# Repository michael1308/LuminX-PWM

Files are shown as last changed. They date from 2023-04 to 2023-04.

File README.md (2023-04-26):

# LuminX-PWM
ESP32-based LED strip driver.

# Features
-   ESP32-WROOM-32E
-   CH340E/G
-   USB C
-   Micro USB for power
-   2.1mm Barrel Jack w/ reversible polarity    
-   Screw Terminal power input
-   Current Measurement w/ INA219/INA180
-   5V Buck Converter
-   3.3V LDO
-   Microphone
-   IR Receiver
-   5x PWM out
-   Power Switching Relay
-   Temperature Sensor DS18B20
-   I2C Connector
-   ESP32 Debug Connector
-   Up to 10A

# Rev 1.0 (03.2023)
## Issues:
- Reverse Polarity Protection MOSFET reversed
- INA180 Resistor too large -> change to 10mOhm
- USBLC6 wrong footprint -> SOT-6

## Changes:
- Remove Micro USB
- Route Input Voltage directly to output
- Change reverse polarity protection to antiparallel diode (M7)
- Better Integration for Temp Sensor
- Smaller Footprint
- Automotive or Glass fuse?

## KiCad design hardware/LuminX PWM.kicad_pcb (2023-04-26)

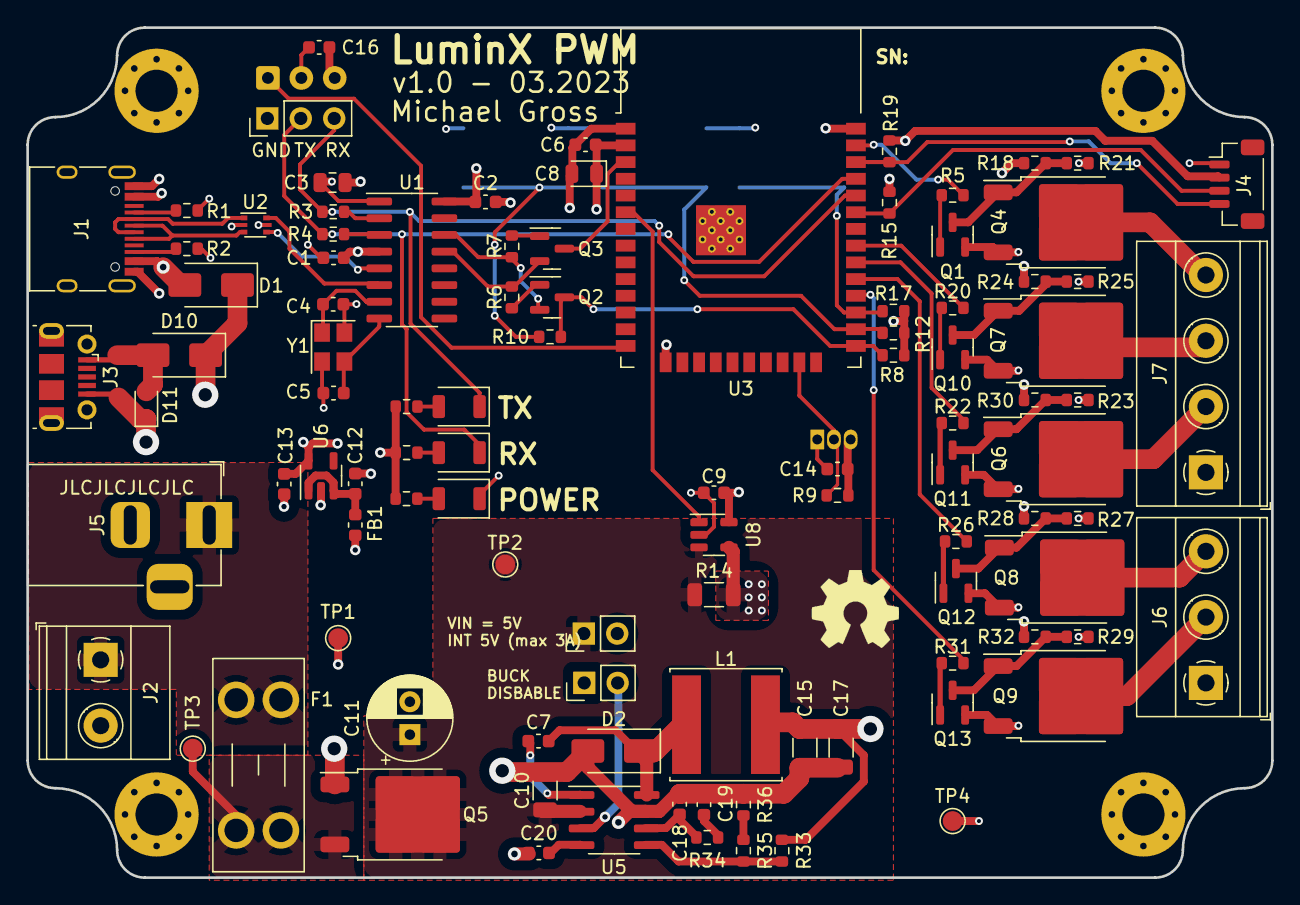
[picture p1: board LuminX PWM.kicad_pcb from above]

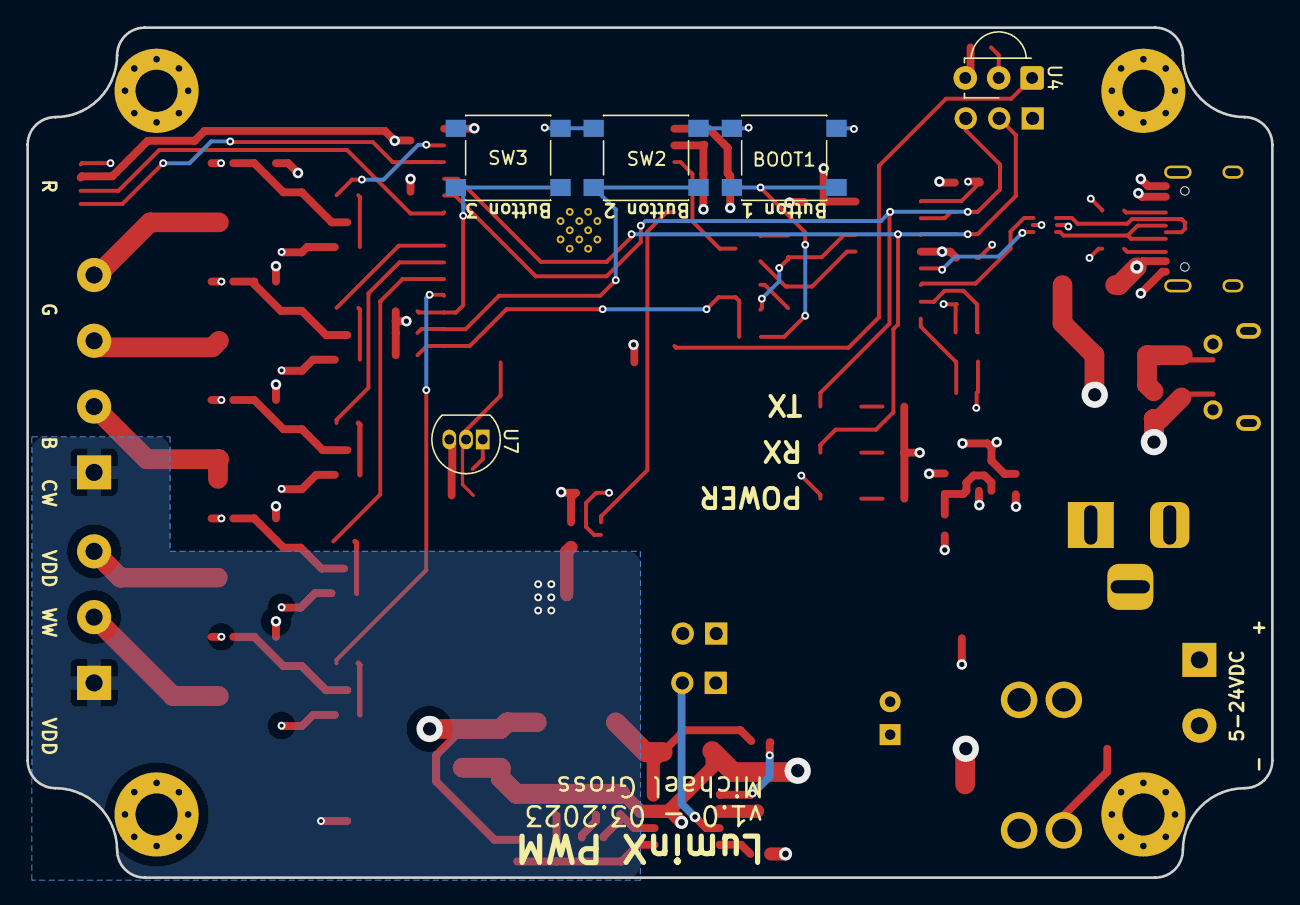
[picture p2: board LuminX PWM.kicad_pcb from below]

Board: 4 copper layers, 94.6 x 64.6 mm, 109 parts (5 on the bottom side), 67 nets.

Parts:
BOOT1: SW_Push; SW_SPST_PTS645
C1, C2, C6, C7, C9, C14, C16: 100n; C_0603_1608Metric
C3: 10u; C_0805_2012Metric
C4, C5: 30p; C_0603_1608Metric
C8: 10u; D_0805_2012Metric
C10: 10u; C_1206_3216Metric
C11: 100u/35V; CP_Radial_D6.3mm_P2.50mm
C12, C13: 1u; C_0603_1608Metric
C15, C17: 22u; C_1206_3216Metric
C18: 10p; C_0603_1608Metric
C19: 1n; C_0603_1608Metric
C20: 8n2; C_0603_1608Metric
D1, D10: SS34; D_SMA
D2: SS54; D_SMA
D4: YELLOW; LED_1206_3216Metric_ReverseMount_Hole1.8x2.4mm
D5, D6: GREEN; LED_1206_3216Metric_ReverseMount_Hole1.8x2.4mm
D11: SD12C; D_SOD-323
F1: 10A; Fuseholder_Blade_Mini_Keystone_3568
FB1: 100R; L_0603_1608Metric
H1, H3, H4: MountingHole; MountingHole_3.2mm_M3_Pad_Via
He: MountingHole; MountingHole_3.2mm_M3_Pad_Via
J1: USB_C_Receptacle_USB2.0; USB_C_Receptacle_HRO_TYPE-C-31-M-12
J2: 5mm Screw Terminal; TerminalBlock_Phoenix_MKDS-1,5-2_1x02_P5.00mm_Horizontal
J3: USB_B_Micro; USB_Micro-B_Molex-105017-0001
J4: Conn_01x04_Pin; JST_SH_BM04B-SRSS-TB_1x04-1MP_P1.00mm_Vertical
J5: Barrel_Jack_Switch; BarrelJack_Horizontal
J6: Screw_Terminal_01x03; TerminalBlock_Phoenix_MKDS-1,5-3_1x03_P5.00mm_Horizontal
J7: 5mm Screw Terminal; TerminalBlock_Phoenix_MKDS-1,5-4_1x04_P5.00mm_Horizontal
J9: Conn_01x03_Pin; PinHeader_1x03_P2.54mm_Vertical
JP1, JP3: Jumper_2_Open; PinHeader_1x02_P2.54mm_Vertical
L1: 10u/3A; L_Sunlord_SWPA8040S
Q1, Q2, Q3, Q10, Q11, Q12, Q13: BC847; SOT-23
Q4, Q6, Q7, Q8, Q9: IRLR8726; TO-252-2
Q5: WSF70P03; TO-252-2
R1, R2: 5k1; R_0603_1608Metric
R3, R4, R10: 470R; R_0603_1608Metric
R5, R11, R13, R16, R20, R22, R26, R31: 1k; R_0603_1608Metric
R6, R7, R8, R9, R12, R17, R18, R24, R28, R30, R32, R33: 10k; R_0603_1608Metric
R14: 0.1R; R_1206_3216Metric
R15, R19: 4k7; R_0603_1608Metric
R21, R23, R25, R27, R29: 100k; R_0603_1608Metric
R34: 33k; R_0603_1608Metric
R35: 1k2; R_0603_1608Metric
R36: 680; R_0603_1608Metric
SW2, SW3: SW_Push; SW_SPST_PTS645
TP1, TP2, TP3, TP4: TestPoint; TestPoint_Pad_D1.5mm
U1: CH340G; SOIC-16_3.9x9.9mm_P1.27mm
U2: USBLC6-2P6; SOT-666
U3: ESP32-WROOM-32D
U4: TSOP382xx; Vishay_MINICAST-3Pin
U5: TPS54332; SOIC-8_3.9x4.9mm_P1.27mm
U6: AP2112K-3.3; SOT-23-5
U7: DS18B20; TO-92_Inline
U8: INA180A1; SOT-23-5
Y1: 12MHz; Crystal_SMD_3225-4Pin_3.2x2.5mm

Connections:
+3V3: C1.1, C2.1, C3.1, C6.1, C8.1, C9.1, C13.1, C14.1, C16.1, J4.2, R8.1, R9.1, R11.1, R12.1, R13.1, R15.1, R16.1, R17.1, R19.1, U1.4 (V3), U1.16 (VCC), U3.2 (VDD), U4.3 (Vs), U6.5 (VOUT), U7.3 (V_{DD}), U8.5 (V+)
+5V: C15.1, C17.1, D1.1 (K), D10.1 (K), FB1.1, JP3.2 (B), L1.2, R18.2, R24.2, R28.2, R30.2, R32.2, R33.2, TP1.1
/ESP32+CH340/CH340_XI: C4.1, U1.7 (XI), Y1.1
/ESP32+CH340/CH340_XO: C5.1, U1.8 (XO), Y1.3
/ESP32+CH340/nDTR: Q3.2 (E), R6.1, U1.13 (~DTR)
/ESP32+CH340/nRTS: Q2.2 (E), R7.1, U1.14 (~RTS)
/Power+USB/D+: J1.A6 (D+), J1.B6 (D+), U2.3 (I/O2)
/Power+USB/D-: J1.A7 (D-), J1.B7 (D-), U2.1 (I/O1)
/Power+USB/VBUS_MICROUSB: D10.2 (A), D11.2 (A2), J3.1 (VBUS)
/Power+USB/VBUS_USBC: D1.2 (A), J1.A4 (VBUS), J1.A9 (VBUS), J1.B4 (VBUS), J1.B9 (VBUS), U2.5 (VBUS)
/Power+USB/VIN_RAW: F1.1, J2.1, J5.1
/Power+USB/VIN_RPP: F1.2, Q5.3 (S), TP3.1
EN: Q3.3 (C), U3.3 (EN)
ESP32_RX: D5.1 (K), J9.3, R3.2, U3.34 (RXD0/IO3)
ESP32_TX: D4.1 (K), J9.2, R4.2, U3.35 (TXD0/IO1)
GND: BOOT1.2, C1.2, C2.2, C3.2, C4.2, C5.2, C6.2, C8.2, C9.2, C10.2, C11.2, C12.2, C13.2, C14.2, C15.2, C16.2, C17.2, C18.2, C19.2, C20.2, D2.2 (A), D6.1 (K), D11.1 (A1), H1.1, H3.1, H4.1, He.1, J1.A1 (GND), J1.A12 (GND), J1.B1 (GND), J1.B12 (GND), J2.2, J3.5 (GND), J4.1, J5.2, J9.1, JP1.1 (A), Q1.2 (E), Q4.3 (S), Q5.1 (G), Q6.3 (S), Q7.3 (S), Q8.3 (S), Q9.3 (S), Q10.2 (E), Q11.2 (E), Q12.2 (E), Q13.2 (E), R1.2, R2.2, R21.1, R23.1, R25.1, R27.1, R29.1, R36.1, SW2.2, SW3.2, U1.1 (GND), U2.2 (GND), U3.1 (GND), U3.15 (GND), U3.38 (GND), U3.39 (GND), U4.2 (GND), U5.7 (GND), U6.2 (GND), U7.1 (GND), U8.2 (GND), Y1.2, Y1.4
IO0: Q2.3 (C), R8.2, R10.1, U3.25 (IO0)
IR_CTRL: U3.14 (IO12), U4.1 (OUT)
unnamed: BOOT1.1, R10.2
unnamed: C19.1, R34.1
unnamed: C7.2, D2.1 (K), L1.1, U5.8 (PH)
unnamed: D4.2 (A), R11.2
unnamed: D5.2 (A), R13.2
unnamed: D6.2 (A), R16.2
unnamed: J1.A5 (CC1), R1.1
unnamed: J1.B5 (CC2), R2.1
unnamed: JP1.2 (B), U5.3 (EN)
unnamed: Q1.1 (B), R5.2
unnamed: Q1.3 (C), Q4.1 (G), R18.1, R21.2
unnamed: Q2.1 (B), R6.2
unnamed: Q3.1 (B), R7.2
unnamed: Q10.1 (B), R20.2
unnamed: Q7.1 (G), Q10.3 (C), R24.1, R25.2
unnamed: Q11.1 (B), R22.2
unnamed: Q6.1 (G), Q11.3 (C), R23.2, R30.1
unnamed: Q12.1 (B), R26.2
unnamed: Q8.1 (G), Q12.3 (C), R27.2, R28.1
unnamed: Q13.1 (B), R31.2
unnamed: Q9.1 (G), Q13.3 (C), R29.2, R32.1
unnamed: R35.1, R36.2
unnamed: R4.1, U1.3 (RXD)
unnamed: R3.1, U1.2 (TXD)
unnamed: C7.1, U5.1 (BOOT)
unnamed: C18.1, R34.2, U5.6 (COMP)
unnamed: C20.1, U5.4 (SS)
unnamed: R33.1, R35.2, U5.5 (VSENSE)
unnamed: C12.1, FB1.2, U6.1 (VIN), U6.3 (EN)
SCL: J4.4, R19.2, U3.36 (IO22)
SDA: J4.3, R15.2, U3.33 (IO21)
SW2: R12.2, SW2.1, U3.26 (IO4)
SW3: R17.2, SW3.1, U3.27 (IO16)
TEMP: R9.2, U3.23 (IO15), U7.2 (DQ)
USB_D+: U1.5 (UD+), U2.4 (I/O2)
USB_D-: U1.6 (UD-), U2.6 (I/O1)
V-_BLUE: J7.2, Q6.2 (D)
V-_CW: J6.3, Q8.2 (D)
V-_GREEN: J7.3, Q7.2 (D)
V-_RED: J7.4, Q4.2 (D)
V-_WW: J6.2, Q9.2 (D)
VIN: C10.1, C11.1, JP3.1 (A), Q5.2 (D), R14.1, TP2.1, U5.2 (VIN), U8.3 (+)
VOUT_LED: J6.1, J7.1, R14.2, TP4.1, U8.4 (-)
V_CTRL_BLUE: R22.1, U3.30 (IO18)
V_CTRL_CW: R26.1, U3.29 (IO5)
V_CTRL_GREEN: R20.1, U3.31 (IO19)
V_CTRL_RED: R5.1, U3.37 (IO23)
V_CTRL_WW: R31.1, U3.28 (IO17)
V_SENSE: U3.6 (IO34), U8.1
